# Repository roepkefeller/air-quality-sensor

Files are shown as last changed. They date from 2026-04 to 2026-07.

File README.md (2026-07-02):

# Air Quality Sensor

A DIY open-source air quality monitor built around an [ESP32-C3-WROOM-02](https://documentation.espressif.com/esp32-c3-wroom-02_datasheet_en.pdf), featuring a custom 4-layer PCB with four Sensirion/Bosch sensors, a laser-cut glass top panel, and a 3D-printed holder. Firmware runs on [ESPHome](https://esphome.io) and integrates natively with Home Assistant.

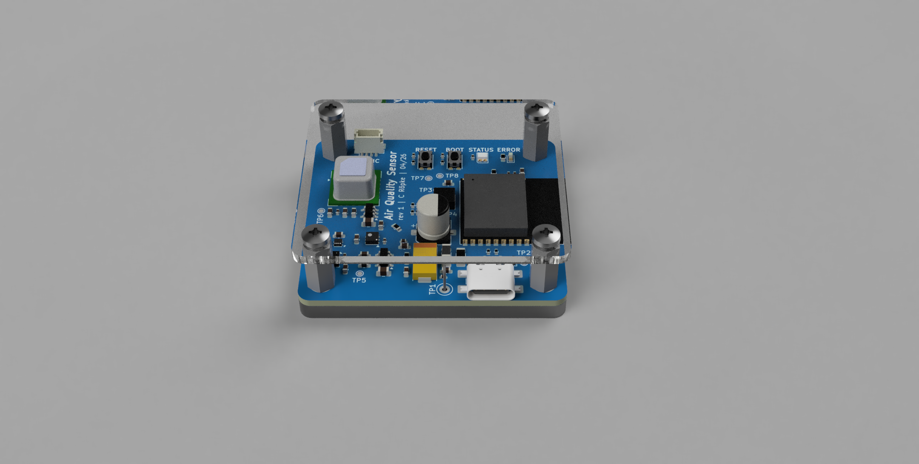
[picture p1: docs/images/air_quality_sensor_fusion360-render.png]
Fusion 360 render


---

## Table of contents

- [What it measures](#what-it-measures)
- [System overview](#system-overview)
- [Hardware design](#hardware-design)
  - [Sensors](#sensors)
  - [Power system](#power-system)
  - [PCB](#pcb)
  - [Enclosure](#enclosure)
- [Assembly](#assembly)
  - [Soldering](#soldering)
  - [I2C addresses](#i2c-addresses)
  - [Power-on checklist](#power-on-checklist)
- [Firmware](#firmware)
  - [Getting started](#getting-started)
  - [LED behavior](#led-behavior)
  - [Web interface](#web-interface)
  - [Diagnostic configs](#diagnostic-configs)
- [Manufacturing](#manufacturing)
- [License](#license)

---

## What it measures

| Sensor | Measurements | Notes | Datasheet |
|---|---|---|---|
| **Sensirion SCD41** | CO₂ (ppm), temperature, humidity | Primary air quality signal | [PDF](https://sensirion.com/media/documents/48C4B7FB/67FE0194/CD_DS_SCD4x_Datasheet_D1.pdf) |
| **Sensirion SGP41** | VOC Index (1–500), NOx Index (1–500) | Fallback if SCD41 unavailable | [PDF](https://sensirion.com/media/documents/5FE8673C/61E96F50/Sensirion_Gas_Sensors_Datasheet_SGP41.pdf) |
| **Sensirion SHT40** | Temperature (±0.2 °C), humidity (±1.8 %RH) | Reference for sensor compensation | [PDF](https://sensirion.com/resource/datasheet/sht4x) |
| **Bosch BMP280** | Barometric pressure, temperature | CO₂ altitude compensation source | [PDF](https://www.bosch-sensortec.com/media/boschsensortec/downloads/datasheets/bst-bmp280-ds001.pdf) |

---

## System overview

System overview diagram

The ESP32-C3 sits at the center of the design. All four sensors share a single I2C bus running at 50 kHz. The BMP280 pressure reading feeds the SCD41's ambient pressure compensation input, and the SHT40 temperature and humidity readings feed the SGP41's gas compensation algorithm. This cross-sensor compensation is why all four sensors are present even though some measurements overlap.

---

## Hardware design

### Sensors

**SCD41 — CO₂**

The SCD41 uses photoacoustic NDIR (non-dispersive infrared) technology to measure CO₂ directly. CO₂ is the primary metric for indoor air quality: levels above 1000 ppm are linked to reduced concentration, and above 2000 ppm cause noticeable cognitive effects. The SCD41 includes automatic self-calibration (ASC), which compensates for long-term sensor drift by assuming the sensor sees outdoor-quality air (≈400 ppm) for at least one hour per day. It also accepts an ambient pressure input from the BMP280 to correct for altitude-induced measurement error.

**SGP41 — VOC and NOx**

The SGP41 uses a metal oxide (MOX) sensing element to detect volatile organic compounds and nitrogen oxides. Rather than reporting raw concentrations, it outputs a processed index (1–500) where 100 represents a typical indoor baseline. This makes it well-suited for detecting events like cooking, cleaning products, paint fumes, or combustion without requiring gas-specific calibration. It also serves as the fallback air quality signal when CO₂ data is unavailable — the LED logic prefers CO₂ but degrades gracefully to VOC index.

**SHT40 — Temperature and humidity (reference)**

The SHT40 is the most accurate temperature and humidity sensor on the board. Its readings feed the SGP41's built-in compensation algorithm, which requires accurate ambient conditions to produce reliable VOC and NOx readings. The SHT40 is also the primary source of temperature and humidity data for the Home Assistant dashboard — the SCD41 and BMP280 both have internal temperature sensors, but they run warmer due to self-heating and are less accurate.

All sensors on this board are affected by self-heating from the SGP41's MOX element (which runs an internal heater at ~400 °C), the ESP32-C3 Wi-Fi radio, and the power regulators. The firmware applies empirically calibrated offset corrections: −5.5 °C / +8 %RH for the SHT40, −5.5 °C for the BMP280, and −1.5 °C / +4 %RH for the SCD41. These values may need tuning — place a known-good reference thermometer next to the board, let everything stabilize for 30+ minutes, and adjust the offsets in the YAML until they match.

**BMP280 — Barometric pressure**

The BMP280 adds barometric pressure, which has two uses: it feeds the SCD41's ambient pressure compensation input (NDIR CO₂ sensors read differently at different altitudes), and it provides weather-correlation data for the Home Assistant dashboard.

---

### Power system

The board takes 5 V via USB-C. Any standard USB-C power supply rated ≥1 A works — no USB Power Delivery negotiation is required, and charge-only cables (no data lines) are fine.

The power path is:

**USB-C → TPD2EUSB30 (ESD protection) → PPTC fuse (750 mA self-resetting) → three separate 3.3 V rails**

Three regulators run in parallel off the 5 V bus, each feeding a dedicated load:

- **[TLV62569A](https://www.ti.com/lit/ds/symlink/tlv62569a.pdf)** (synchronous buck converter) → ESP32-C3 and QWIIC connector. The buck is efficient for the ESP32's variable current draw. The QWIIC connector shares this rail, keeping the sensitive sensor LDO rails free from expansion board loads.
- **[TLV755P](https://www.ti.com/lit/ds/symlink/tlv755p.pdf)** (LDO) → SCD41. The SCD41's photoacoustic CO₂ measurement is sensitive to supply noise; a dedicated LDO with a higher current rating than the TPS7A20 keeps its rail clean and isolated.
- **[TPS7A20](https://www.ti.com/lit/ds/symlink/tps7a20.pdf)** (ultra-low-noise LDO, 10 µVRMS) → SGP41, SHT40, and BMP280. The SGP41's MOX element and SHT40's capacitive humidity sensor are especially susceptible to supply noise; the TPS7A20 keeps all three on a single clean rail, isolated from both the buck and the SCD41's LDO.

The **PPTC fuse** is a self-resetting polyfuse rated at 750 mA, protecting the board against overcurrent faults without requiring manual intervention.

---

### PCB

<table>
  <tr>
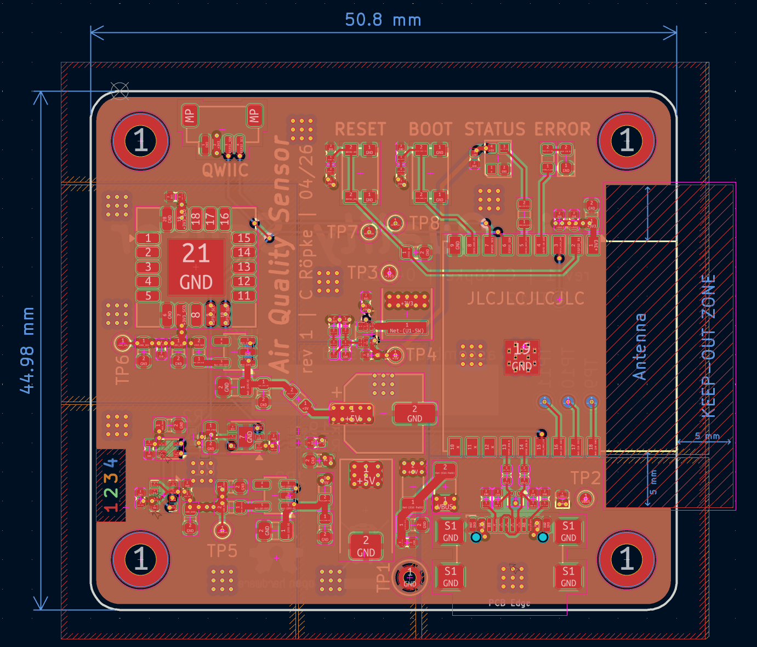
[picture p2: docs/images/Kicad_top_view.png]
KiCad top copper layer
    <td></td>
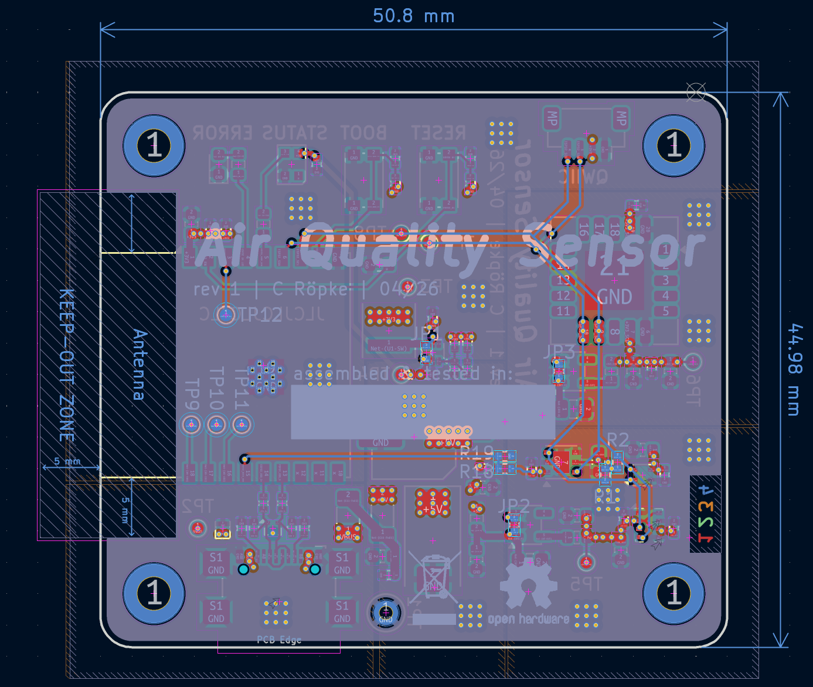
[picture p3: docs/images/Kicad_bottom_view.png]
KiCad bottom copper layer
    <td></td>
  </tr>
  <tr>
    <td align="center"><em>Top copper layer</em></td>
    <td align="center"><em>Bottom copper layer</em></td>
  </tr>
</table>

<table>
  <tr>
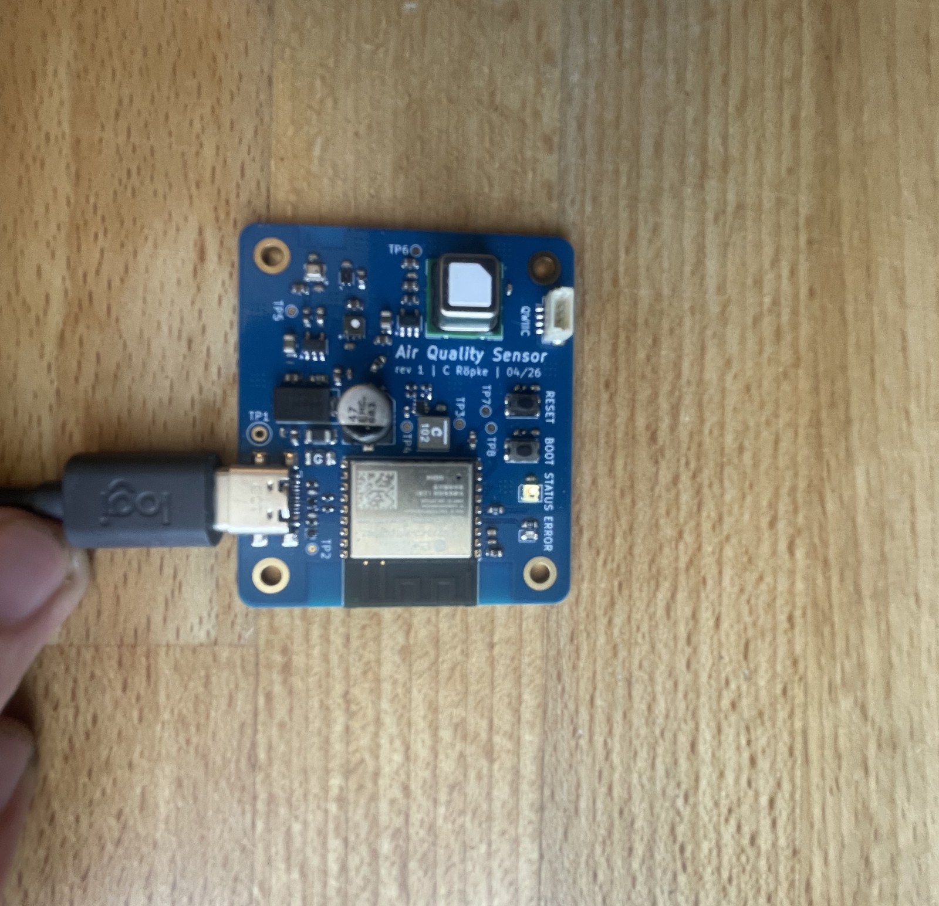
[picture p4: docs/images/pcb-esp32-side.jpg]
PCB component side — ESP32 and sensors
    <td></td>
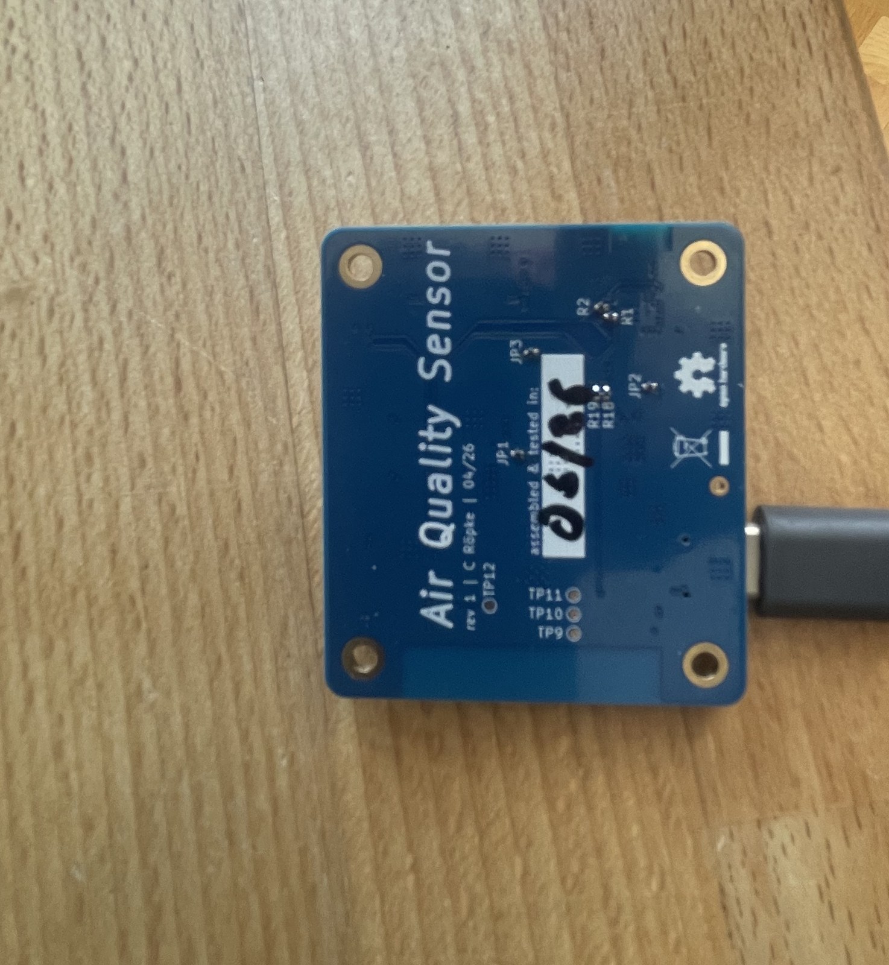
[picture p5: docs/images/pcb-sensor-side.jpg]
PCB bottom side — silkscreen
    <td></td>
  </tr>
  <tr>
    <td align="center"><em>Component side — ESP32, SCD41, regulators</em></td>
    <td align="center"><em>Bottom side — silkscreen</em></td>
  </tr>
</table>

The PCB is a 4-layer board designed in [KiCad](https://www.kicad.org/). Bare boards were manufactured by [JLCPCB](https://jlcpcb.com/) and assembled by hand.

Layer stackup: signal / GND plane / power plane / signal. The dedicated ground and power planes provide clean returns and reduce radiated noise — important given the sensitive gas sensors on the same board.

The board uses a mix of 0402 and 0603 passives, with all ICs in small SMD packages. The custom footprint for the SGP41 (`air_quality_footprints.pretty/`) is included in the repository because it is not in the standard KiCad library.

---

### Enclosure

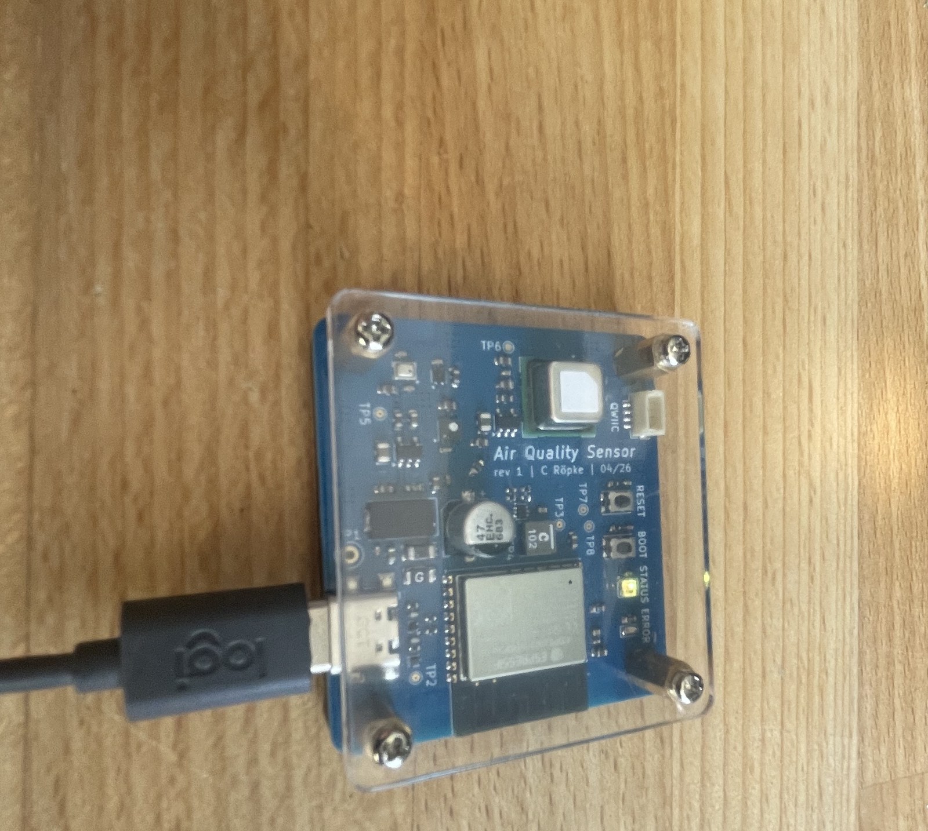
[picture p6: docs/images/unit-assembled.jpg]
Full unit assembled


The enclosure consists of three parts:

**3D-printed holder** (`hardware/enclosure/air_quality_sensor_holder.f3d`, `.stl`): holds the PCB and provides ventilation for the sensors. Print in PLA or PETG at 0.2 mm layer height.

**Laser-cut glass top** (`hardware/enclosure/air_quality_sensor_glass_top.dxf`, `.step`, `.f3d`): 2 mm clear glass, sourced from [Formulor](https://www.formulor.de) using the provided DXF file.

**Standoffs**: [M2.5 × 10 mm male-female hex standoffs](https://www.amazon.de/dp/B0C1FY87PY) (5 mm across flats) mount between the PCB and the glass top. The Fusion 360 model is included at `hardware/enclosure/Standoff mf - M2.5 x 10 across flats 5mm.f3d`.

**Heated inserts**: [M2.5 heat-set inserts](https://www.amazon.de/dp/B0F2TGGBMC) are pressed into the 3D-printed holder with a soldering iron before screwing in the standoffs. This gives the plastic threads much better durability than screwing directly into printed material.

**Power supply and cable**: 5 V/1 A USB-A wall charger + USB-C to USB-A cable. Any charger rated ≥1 A works. Tested with: [RAVIAD USB-C Kabel 1 m (€3.99)](https://www.amazon.de/gp/product/B0GT379MW7) and [18W USB-A Ladegerät, 4er-Pack (€19.98)](https://www.amazon.de/gp/product/B0CRS1YX4S).
<!-- TODO: add photo of USB-C cable + power supply -->

---

## Assembly

### Soldering

All components are SMD. The board was assembled by hand with a soldering iron, flux, and solder paste on the fine-pitch ICs.

Recommended soldering order — smallest and most heat-sensitive first, connectors last:

1. **ESP32-C3-WROOM-02** — the largest IC; solder the pads around the perimeter, then reflow the exposed pad underneath with a hot-air station or by heating the board from below.
2. **TLV62569A, TLV755P, TPS7A20, TPD2EUSB30** — small SOT/WSON packages; drag-solder or use solder paste + hot air.
3. **SGP41** — custom footprint (`air_quality_footprints.pretty/`); ensure the exposed pad underneath is soldered for both mechanical and thermal contact.
4. **SCD41, SHT40, BMP280** — Sensirion LCC packages; reflow carefully, avoid excess heat on the SCD41 optical aperture.
5. **0402/0603 passives** — resistors and capacitors.
6. **USB-C connector, WS2812, LEDs, standoff holes** — connectors and through-board components last.

Use the interactive BOM (`hardware/pcb/air_quality_sensor/bom/ibom.html`) during assembly — it highlights each component on the board overlay and is the easiest way to avoid placing components in the wrong location. Open it locally in any browser, no server required.

The schematic PDF (`hardware/pcb/air_quality_sensor/air_quality_sensor-schematic.pdf`) is the reference for component values and net names.

### I2C addresses

| Sensor | I2C address | Configurable? |
|---|---|---|
| SCD41 | 0x62 | No |
| SGP41 | 0x59 | No |
| SHT40 | 0x44 | No |
| BMP280 | 0x76 | Via SDIO pin (0x76 or 0x77) |

The firmware enables I2C bus scanning on boot (`scan: true`). With a serial monitor connected, boot log output will list all detected addresses — a quick way to confirm all four sensors are soldered correctly and communicating before flashing the full config.

### Power-on checklist

Before flashing for the first time:

1. **Visual inspection** — check for solder bridges on the ESP32 and sensor pads under magnification.
2. **Continuity check** — verify no short between the three 3.3V rails, and no short between any rail and GND.
3. **Apply 5V via USB-C** — measure voltage on each 3.3V rail with a multimeter before the ESP32 is powered. Expected: ~3.3V on all three rails.
4. **Check quiescent current** — with sensors powered but ESP32 not yet flashed, current draw should be low (a few mA). A high reading suggests a solder bridge or incorrect component.
5. **Flash firmware** — once voltage rails check out, proceed to the firmware getting started section.
6. **Verify I2C scan** — open the serial monitor and confirm all four sensor addresses appear in the boot log.

---

## Firmware

The firmware is a single [ESPHome](https://esphome.io) YAML configuration. ESPHome compiles it to a native binary for the ESP32-C3 and handles OTA updates, the web server, and the Home Assistant native API automatically.

### Getting started

**Prerequisites:** ESPHome installed (`pip install esphome` or via the Home Assistant add-on).

1. Copy `firmware/secrets.yaml.example` to `firmware/secrets.yaml` and fill in all four values:

   ```yaml
   wifi_ssid: "your-network"
   wifi_password: "your-password"
   api_encryption_key: "your-base64-encryption-key"
   ota_password: "your-ota-password"
   ```

   The `api_encryption_key` is a 32-byte random key used to encrypt the connection between ESPHome and Home Assistant. Generate one with:

   ```bash
   openssl rand -base64 32
   ```

   Alternatively, run `esphome wizard firmware/air-quality-sensor.yaml` and ESPHome will generate and fill in all secrets interactively.

   The `ota_password` can be any string — you'll be prompted for it when pushing firmware updates over the air.

2. Flash via USB (first time):

   ```bash
   cd firmware
   esphome run air-quality-sensor.yaml
   ```

3. All subsequent updates are over-the-air automatically.

**Home Assistant:** once on the network the device is auto-discovered via the native API. Go to Settings → Integrations and accept the discovered device. All sensors, the fault indicator, and the LED control appear as entities immediately.

---

### LED behavior

The WS2812 RGB LED on the board gives an at-a-glance air quality reading. The firmware prefers CO₂ from the SCD41 as the primary signal; if that sensor is unavailable, it falls back to the VOC index from the SGP41.

| Color | CO₂ (preferred) | VOC Index (fallback) |
|---|---|---|
| 🟢 Green | < 800 ppm | < 150 |
| 🟡 Yellow | 800–1200 ppm | 150–250 |
| 🔴 Red | > 1200 ppm | > 250 |

Brightness defaults to 25% on first boot and is then fully user-controlled from Home Assistant. The chosen brightness persists across reboots. The LED can also be turned on/off from HA — the on/off state persists independently of brightness. Color updates are intentionally instant (no transition fade) so the reading snaps to the new value as soon as a sensor reports.

The LED driver is activated 5 seconds after boot to avoid a crash in the WS2812 driver before its internal buffer is initialized. During this window the LED stays off regardless of sensor data.

A second red LED (the fault LED) lights up whenever any sensor stops reporting valid data. It re-evaluates every 30 seconds as a backstop against sensors going silently missing.

---

### Web interface

The device runs a built-in web server on port 80. Navigate to `http://air-quality-sensor.local` (or the device's IP) in any browser on the same network to see all sensor readings and control buttons without Home Assistant.

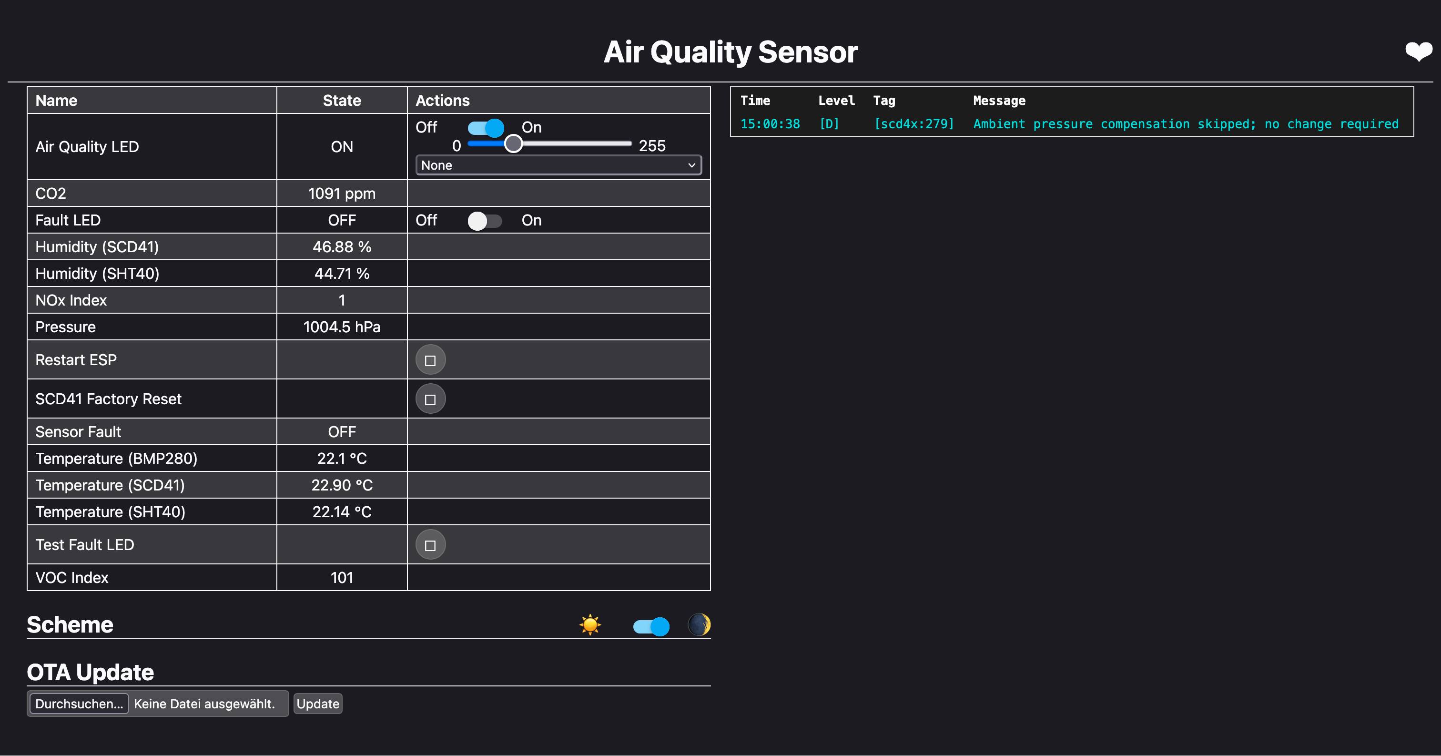
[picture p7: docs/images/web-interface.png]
Web interface


Diagnostic buttons available in the web UI and in Home Assistant:

| Button | Effect |
|---|---|
| **SCD41 Factory Reset** | Clears the SCD41's calibration history and restarts the ESP32. Use if the CO₂ readings look wrong after a long transport or storage period. |
| **Test Fault LED** | Turns the fault LED on for 2 seconds — useful for confirming the LED is soldered and working. |
| **Restart ESP** | Reboots the ESP32. |

If the device cannot reach your Wi-Fi network it falls back to an access point: SSID `Air-Quality Fallback`, password `configureme`. Connect to it and navigate to `http://192.168.4.1` to reconfigure.

---

### Diagnostic configs

Two additional ESPHome configs are included for debugging the SCD41:

| File | Purpose |
|---|---|
| `diagnostic-scd41-only.yaml` | Runs only the SCD41 in isolation — useful for ruling out I2C address conflicts |
| `diagnostic-scd41-deep.yaml` | Extended SCD41 diagnostics with verbose sensor logging |

Flash a diagnostic config the same way as the main config:

```bash
esphome run firmware/diagnostic-scd41-only.yaml
```

---

## Manufacturing

PCB production files are in `hardware/pcb/air_quality_sensor/jlcpcb/`:

| File | Purpose |
|---|---|
| `gerber/GERBER-air_quality_sensor.zip` | Upload to JLCPCB (or any fab) to order the bare PCB |
| `production_files/BOM-air_quality_sensor.csv` | Bill of materials — use for sourcing components |
| `production_files/CPL-air_quality_sensor.csv` | Component placement file — reference for hand assembly positioning |

Order the bare PCB from JLCPCB using the Gerber zip. Source components separately (Mouser, LCSC, DigiKey) using the BOM, then assemble by hand — see the [Assembly](#assembly) section above for the recommended process.

The schematic PDF (`hardware/pcb/air_quality_sensor/air_quality_sensor-schematic.pdf`) and interactive BOM (`bom/ibom.html`) are the primary references during assembly.

---

## License

Hardware (PCB schematics, layout, enclosure files) is licensed under the [CERN Open Hardware Licence Version 2 – Strongly Reciprocal (CERN-OHL-S-2.0)](https://ohwr.org/cern_ohl_s_v2.txt).

Firmware is licensed under the [MIT License](https://opensource.org/licenses/MIT).

In short: you can use, modify, and manufacture this design freely — including commercially — as long as any modifications to the hardware are released under the same licence.

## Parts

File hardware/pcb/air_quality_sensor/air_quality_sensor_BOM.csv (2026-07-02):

Reference | Qty | DNP | Footprint | Manufacturer (MFR) | Value | Manufacturer Part Number (MPN) | Datasheet | Comments
C1 | 1 |  | Capacitor_SMD:C_0402_1005Metric | KYOCERA AVX | 4.7µ/10V/X5R | 0402ZD475KAT2A
C2,C3,C5,C12,C13,C21,C22,C25,C30,C31,C34 | 11 |  | Capacitor_SMD:C_0402_1005Metric | YAGEO | 100n/10V/X5R | CC0402KPX5R6BB104
C4,C9 | 2 |  | Capacitor_SMD:C_0402_1005Metric | KEMET | 10p/10V/C0G | C0402C100J8GACTU
C6,C29 | 2 |  | Capacitor_SMD:C_0402_1005Metric | Murata | 22µ/10V/X5R | GRM158R61A226ME15D
C7,C8,C11,C17,C18,C19,C20,C24,C26,C28,C32,C33 | 12 |  | Capacitor_SMD:C_0603_1608Metric | YAGEO | 1µ/10V/X5R | CC0603KRX5R6BB105
C10 | 1 | DNP | Capacitor_SMD:C_0402_1005Metric | KEMET | 10p/10V/C0G | C0402C100J8GACTU
C14,C27 | 2 |  | Capacitor_SMD:C_0805_2012Metric | Murata | 47µ/10V/X5R | GRM21BR61A476ME15L
C15 | 1 |  | Capacitor_Tantalum_SMD:CP_EIA-7343-20_Kemet-V | Kyocera AVX | 100µ/16V | TCJY107M016R0050
C16 | 1 |  | Capacitor_SMD:C_0402_1005Metric | YAGEO | 1µ/10V/X5R | CC0402KPX5R6BB104
C23 | 1 |  | Capacitor_SMD:CP_Elec_6.3x7.7 | Panasonic | 47u/16V/20% | EEE-HC1E470XP
D1 | 1 |  | Diode_SMD:D_SOD-882 | ST Microelectronics | ESDALC5 | ESDALC5-1BM2 | kicad-embed://esdalc5-1bm2.pdf
D2 | 1 |  | LED_SMD:LED_0603_1608Metric | LITEON | LED 0603 red | LTST-C190EKT | https://www.mouser.com/catalog/specsheets/lite-on_lites05751-1.pdf
D3 | 1 |  | LED_SMD:LED_WS2812B-2020_PLCC4_2.0x2.0mm | Worldsemi | WS2812 | WS2812B-2020 | https://cdn-shop.adafruit.com/product-files/4684/4684_WS2812B-2020_V1.3_EN.pdf
F1 | 1 |  | Fuse:Fuse_1206_3216Metric | Littelfuse | PPTC 8V 750mA | 1206L075THYR | https://www.littelfuse.com/assetdocs/resettable-ptcs-1206l-datasheet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
FB1,FB3 | 2 |  | Inductor_SMD:L_0603_1608Metric | Murata Electronics | 1k@100MHz | BLM18KG102SN1D | https://www.lcsc.com/datasheet/C160982.pdf
FB2 | 1 |  | Inductor_SMD:L_1206_3216Metric | Murata Electronics | 1k@100MHz | BLM31KN102SH1L | https://www.mouser.de/datasheet/3/76/1/QNFA9148.pdf
J1 | 1 |  | Connector_USB:USB_C_Receptacle_GCT_USB4110 | GCT | USB4110 | USB4110-GF-A | https://www.usb.org/sites/default/files/documents/usb_type-c.zip
J2 | 1 |  | Connector_JST:JST_SH_BM04B-SRSS-TB_1x04-1MP_P1.00mm_Vertical | JST | QWIIC Connector | BM04B-SRSS-TB(LF)(SN)
JP1,JP2,JP3 | 3 |  | Resistor_SMD:R_0402_1005Metric |  | 0/1%
L1 | 1 |  | Inductor_SMD:L_Coilcraft_XxL4020 | Coilcraft | 1uH/20%/9.6A | XEL4020-102MEC | https://4donline.ihs.com/images/VipMasterIC/IC/COLC/COLC-S-A0011921176/COLC-S-A0012448959-1.pdf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
R1,R2 | 2 |  | Resistor_SMD:R_0402_1005Metric |  | 4.7k/1%
R3,R9 | 2 |  | Resistor_SMD:R_0402_1005Metric |  | 22/1%
R4,R5 | 2 |  | Resistor_SMD:R_0402_1005Metric |  | 5.1k/1%
R6 | 1 |  | Resistor_SMD:R_0402_1005Metric |  | 270k/1%
R7 | 1 |  | Resistor_SMD:R_0402_1005Metric |  | 180k/1%
R8 | 1 |  | Resistor_SMD:R_0402_1005Metric |  | 100k/1%
R10,R12 | 2 |  | Resistor_SMD:R_0603_1608Metric |  | 330/1%
R11 | 1 |  | Resistor_SMD:R_0603_1608Metric |  | 36/1%
R13 | 1 |  | Resistor_SMD:R_0603_1608Metric |  | 0/1%
R14,R15,R18,R19 | 4 |  | Resistor_SMD:R_0402_1005Metric |  | 10k/1%
SW1,SW2 | 2 |  | Button_Switch_SMD:SW_Push_1P1T_NO_CK_KMR2 | C&K | Push_Button | KMR621NG_LFS | https://www.ckswitches.com/media/1907/kmr6.pdf
U1 | 1 |  | Package_TO_SOT_SMD:SOT-563 | Texas Instruments | TLV62569A | TLV62569ADRLT | https://www.ti.com/lit/gpn/tlv62569a
U2 | 1 |  | Sensor_Humidity:Sensirion_DFN-4_1.5x1.5mm_P0.8mm_SHT4x_NoCentralPad | Sensirion | SHT40 | SHT40-AD1B-R2 | https://www.mouser.de/datasheet/3/1278/1/HT_DS_Datasheet_SHT4x_5.pdf
U3 | 1 |  | Package_LGA:Bosch_LGA-8_2x2.5mm_P0.65mm_ClockwisePinNumbering | Bosch Sensortec | BMP280 | BMP280 | https://cdn-shop.adafruit.com/datasheets/BST-BMP280-DS001-11.pdf
U4 | 1 |  | Package_TO_SOT_SMD:Texas_DRT-3 | Texas Instruments | TPD2EUSB30 | TPD2EUSB30DRTR | http://www.ti.com/lit/ds/symlink/tpd2eusb30a.pdf
U5 | 1 |  | Sensor:Sensirion_SCD4x-1EP_10.1x10.1mm_P1.25mm_EP4.8x4.8mm | Sensirion | SCD41 | SCD41-D-R2 | https://sensirion.com/media/documents/E0F04247/631EF271/CD_DS_SCD40_SCD41_Datasheet_D1.pdf | very temperature sensitive! Use low-temp solder paste!
U6 | 1 |  | air_quality_footprints:XDCR_SGP41-D-R4 | Sensirion | SGP41 | SGP41-D-R4 | https://sensirion.com/media/documents/5FE8673C/61E96F50/Sensirion_Gas_Sensors_Datasheet_SGP41.pdf
U7 | 1 |  | Package_TO_SOT_SMD:SOT-23-5 | Texas Instruments | TPS7A20 | TPS7A2033PDBVR | https://www.ti.com/lit/ds/symlink/tps7a20.pdf
U8 | 1 |  | RF_Module:ESP32-C3-WROOM-02 | Espressif | ESP32-C3-WROOM-02 | ESP32-C3-WROOM-02 | https://www.espressif.com/sites/default/files/documentation/esp32-c3-wroom-02_datasheet_en.pdf
U9 | 1 |  | Package_TO_SOT_SMD:SOT-23-5 | Texas Instruments | TLV75533P | TLV75533PDBVR | https://www.ti.com/lit/ds/symlink/tlv755p.pdf | Alternative: Diodes Inc. AP2112K-3.3TRG1

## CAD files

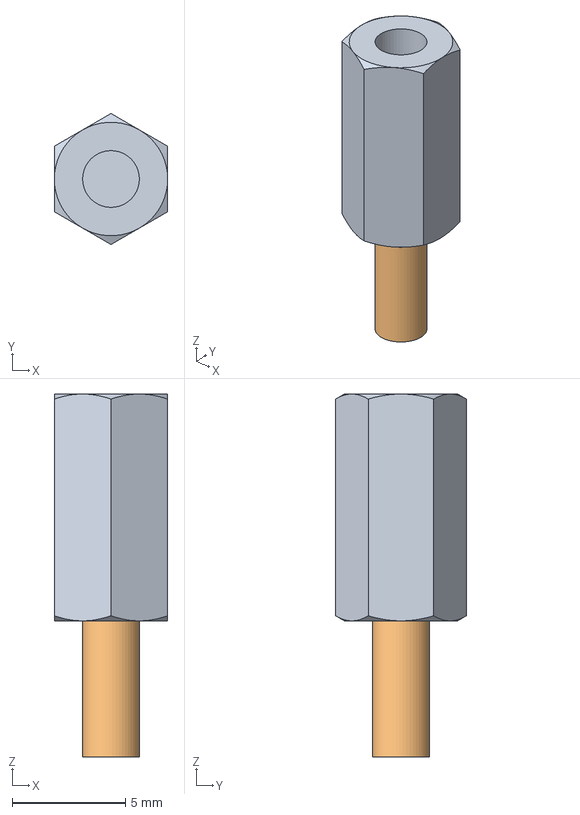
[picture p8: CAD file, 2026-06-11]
hardware/enclosure/Standoff mf - M2.5 x 10 across flats 5mm.step
5.00 x 5.77 x 16.0 mm

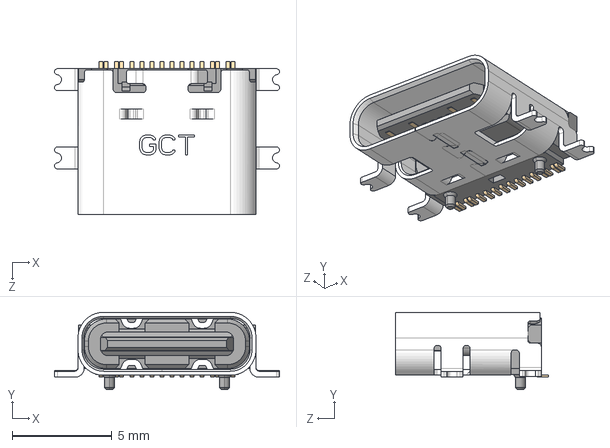
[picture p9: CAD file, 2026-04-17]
hardware/pcb/air_quality_sensor/3dmodels/USB4110-GF-A.step
11.3 x 3.89 x 7.70 mm

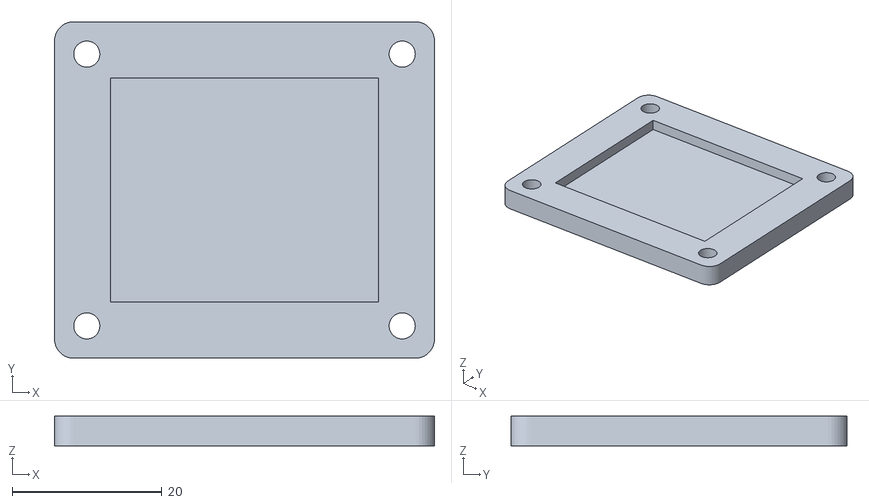
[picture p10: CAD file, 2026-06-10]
hardware/enclosure/air_quality_sensor_holder.stl
50.8 x 45.0 x 4.00

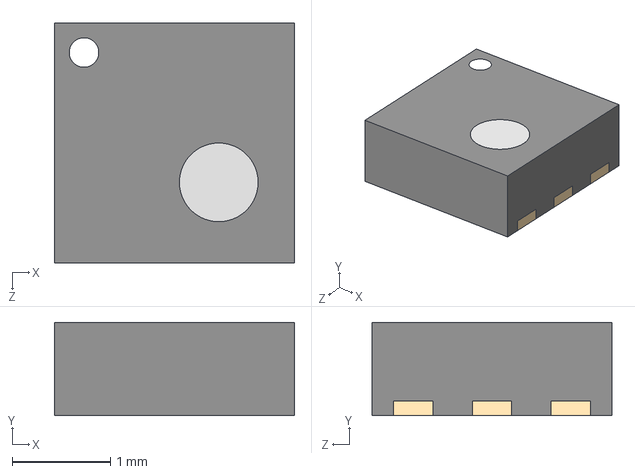
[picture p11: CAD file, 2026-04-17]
hardware/pcb/air_quality_sensor/3dmodels/SGP41-D-R4.step
2.44 x 0.95 x 2.44 mm

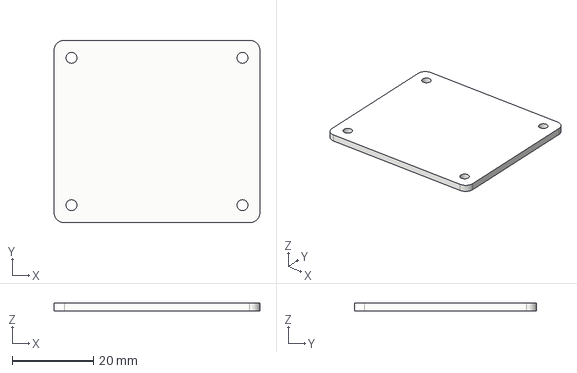
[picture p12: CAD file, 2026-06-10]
hardware/enclosure/air_quality_sensor_glass_top.step
50.8 x 45.0 x 2.00 mm

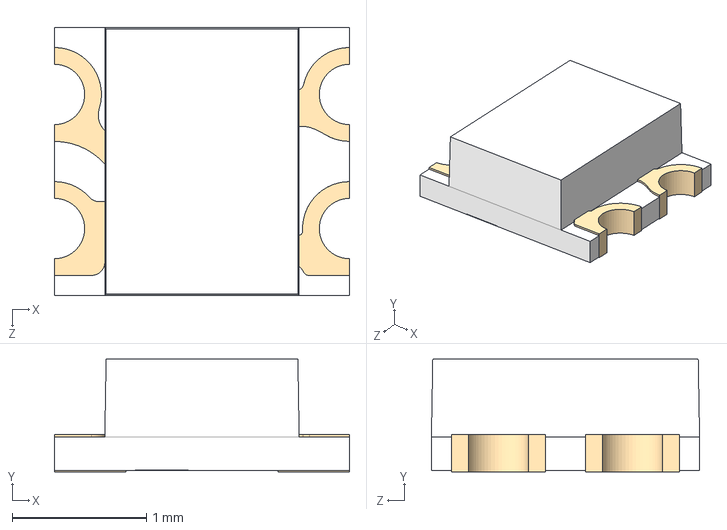
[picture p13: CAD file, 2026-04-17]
hardware/pcb/air_quality_sensor/3dmodels/WS2812-2020--3DModel-STEP-1.STEP
2.20 x 0.84 x 2.00 mm

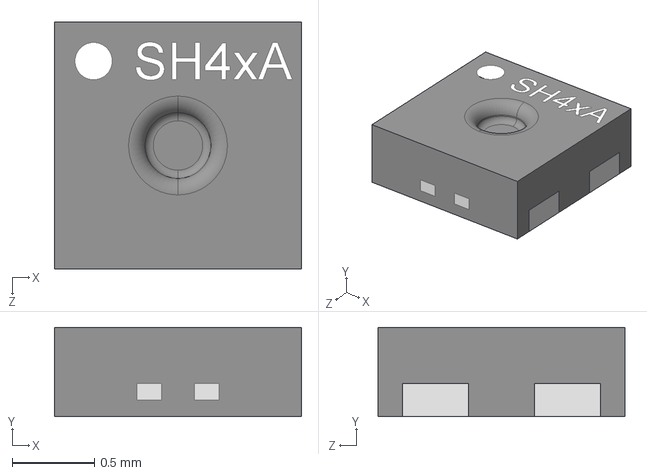
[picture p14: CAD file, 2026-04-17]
hardware/pcb/air_quality_sensor/3dmodels/SHT40-AD1B-R3.STEP
1.50 x 0.541 x 1.50 mm

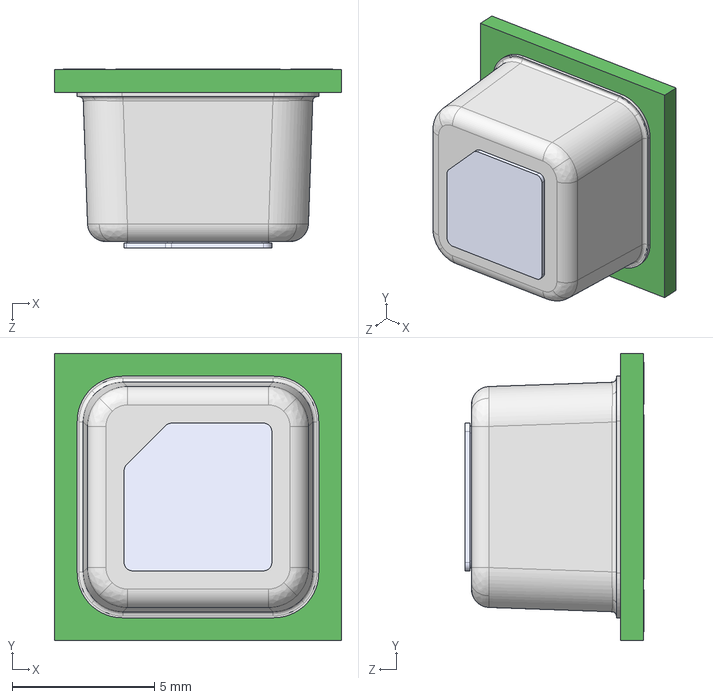
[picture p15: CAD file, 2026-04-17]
hardware/pcb/air_quality_sensor/3dmodels/SCD41-D-R2--3DModel-STEP-369182.STEP
10.1 x 10.1 x 6.31 mm

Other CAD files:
hardware/enclosure/air_quality_sensor_glass_top.dxf
hardware/enclosure/air_quality_sensor_glass_top.f3d
hardware/enclosure/air_quality_sensor_holder.f3d

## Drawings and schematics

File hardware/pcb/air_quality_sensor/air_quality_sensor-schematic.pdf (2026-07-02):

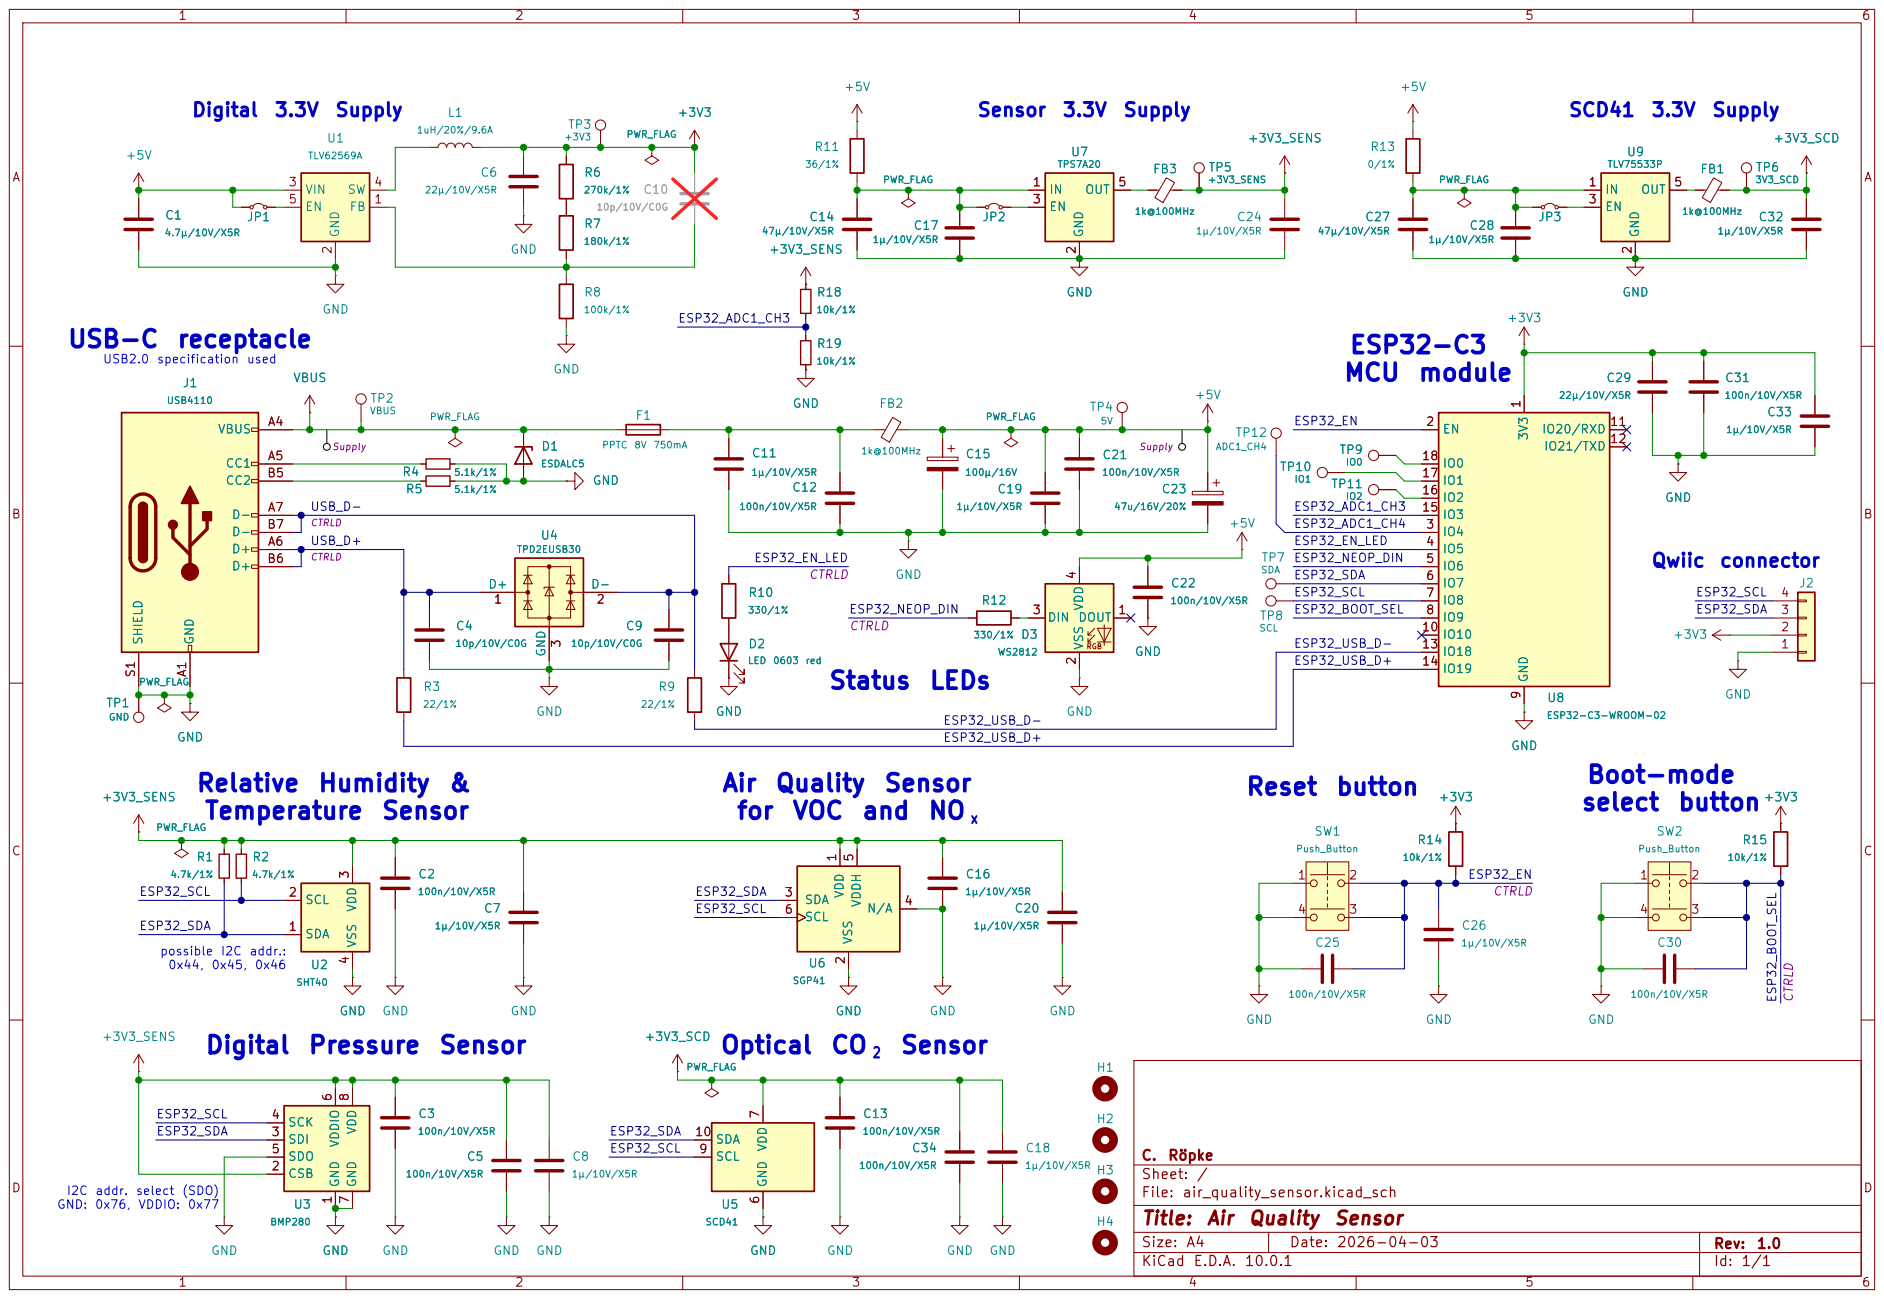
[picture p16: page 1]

Air Quality Sensor
for VOC and NO x Optical CO 2 Sensor
SGP41 VDD

I2C addr. select (SDO) GND: 0x76, VDDIO: 0x77

Size: A4 | Rev: 1.0
KiCad E.D.A. 10.0.1 | Id: 1/1

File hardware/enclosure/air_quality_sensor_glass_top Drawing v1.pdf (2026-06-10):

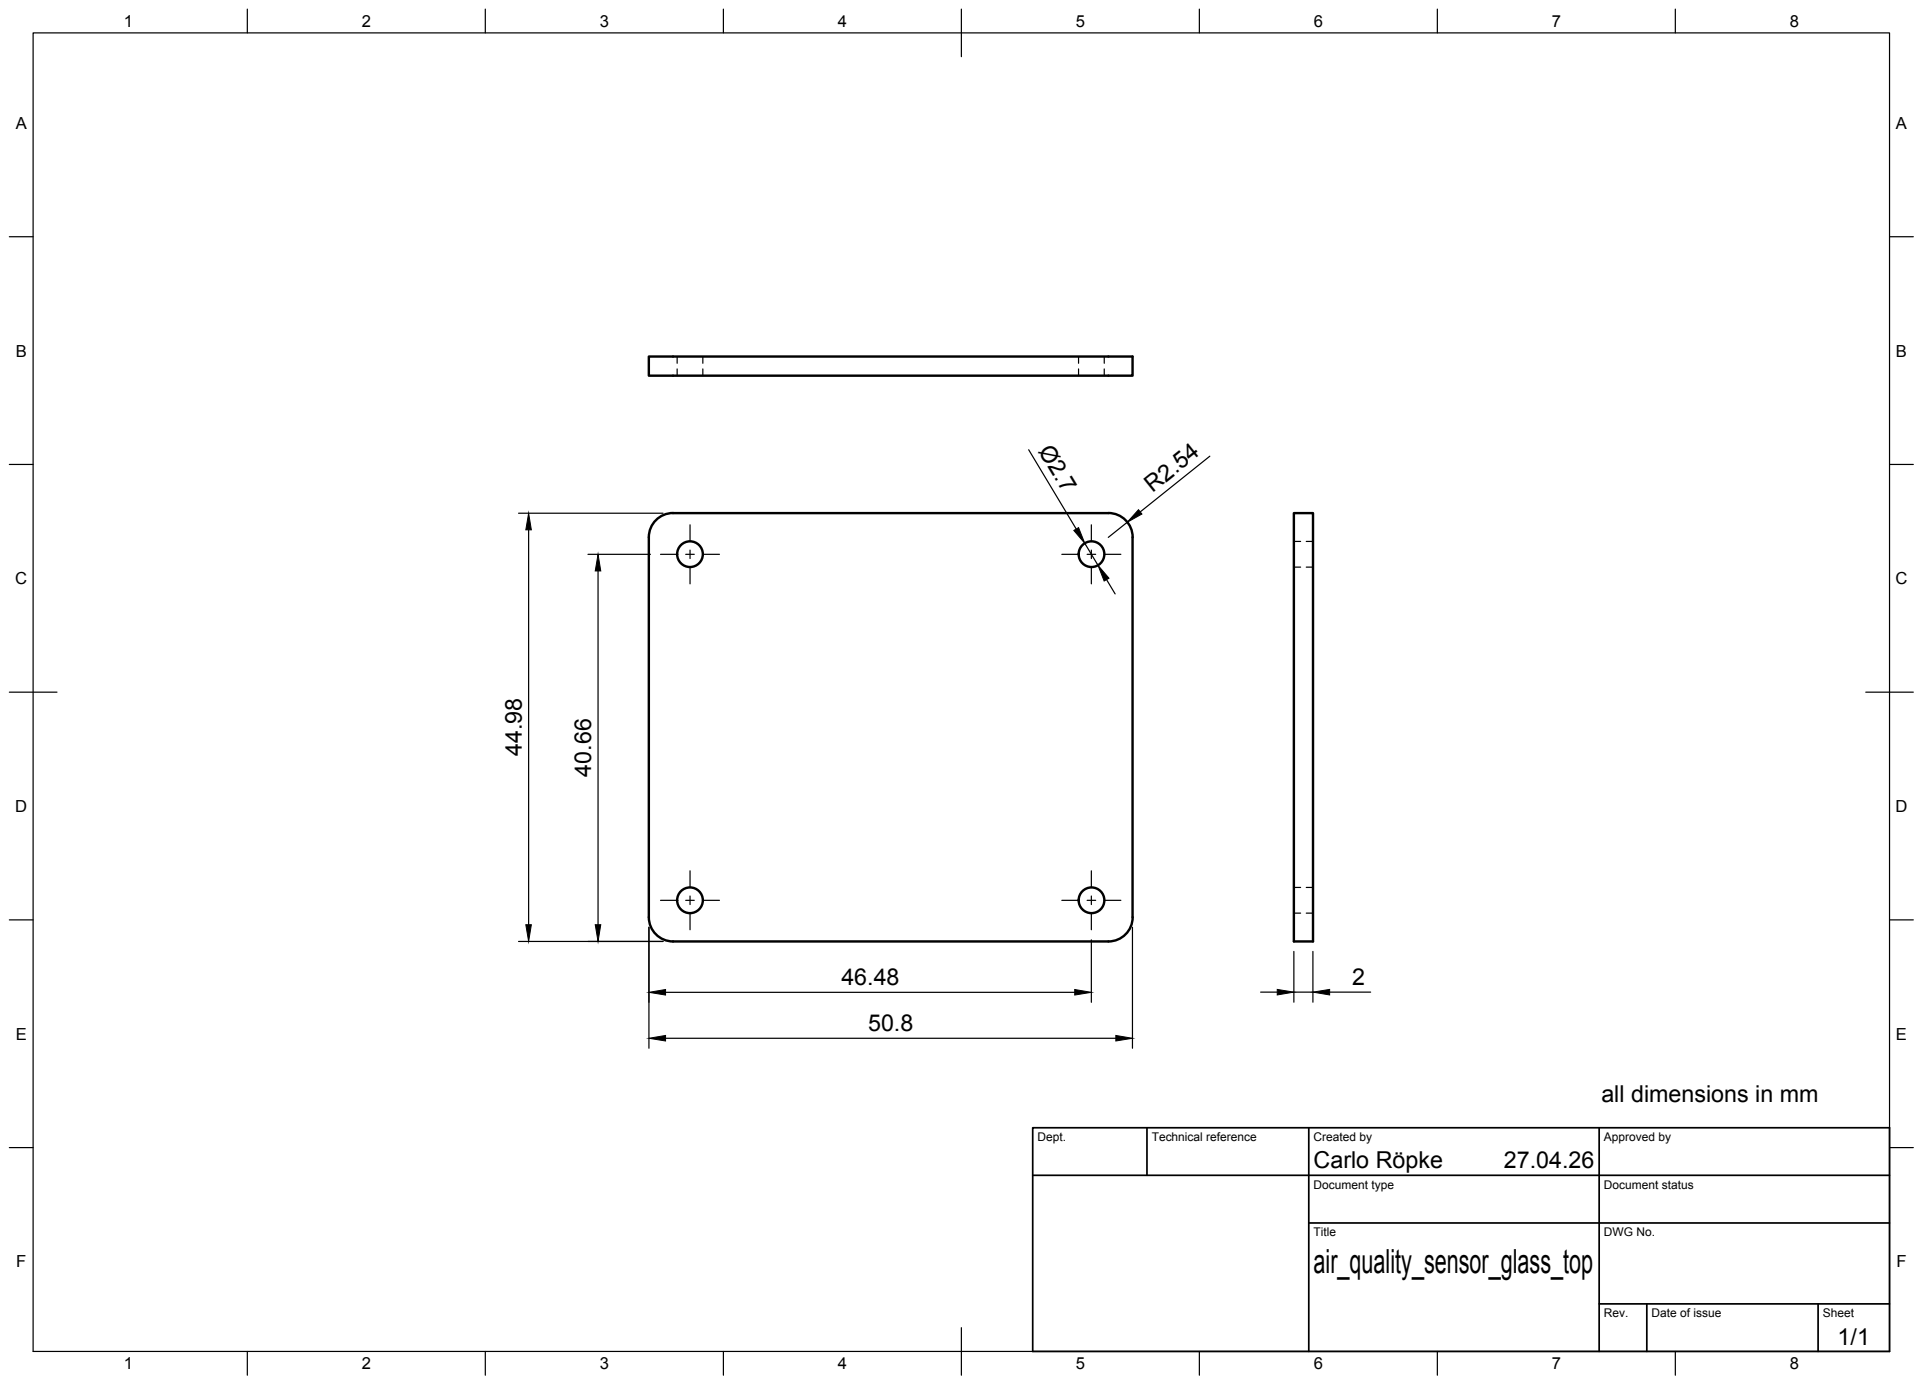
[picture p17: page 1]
Title; DWG No.; Rev.; Date of issue; Sheet

all dimensions in mm

Dept. | Technical reference | Created by Carlo Röpke 27.04.26 | Approved by

Document type | Document status

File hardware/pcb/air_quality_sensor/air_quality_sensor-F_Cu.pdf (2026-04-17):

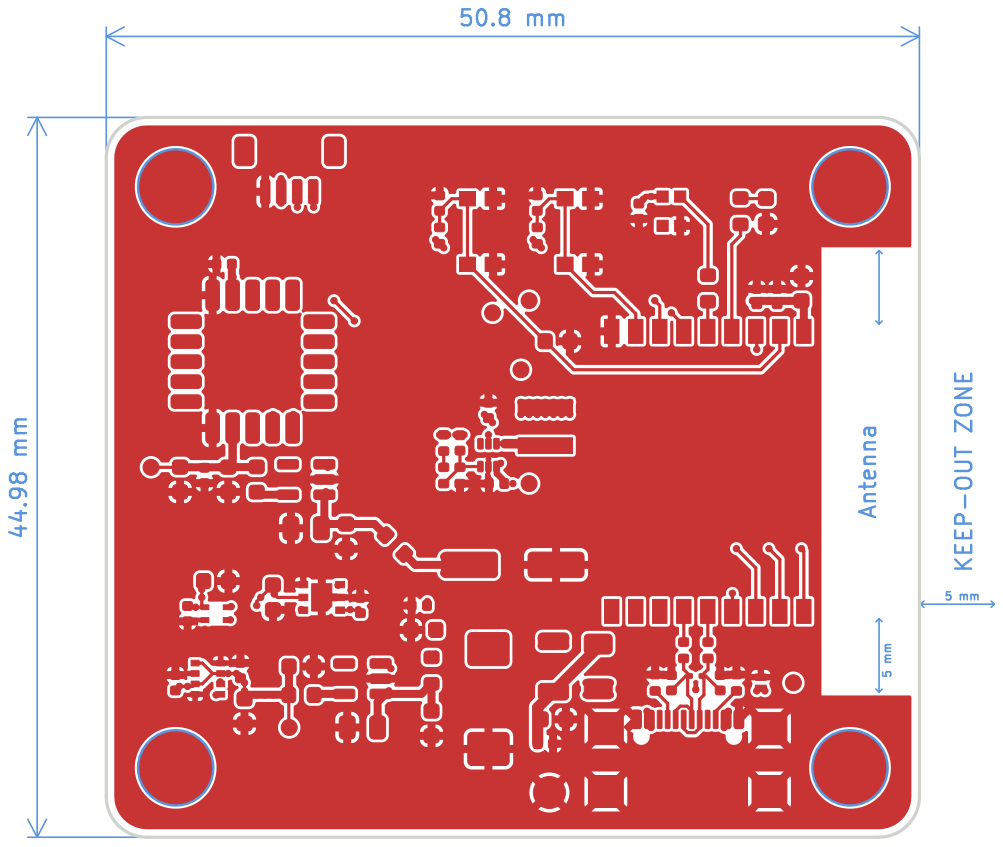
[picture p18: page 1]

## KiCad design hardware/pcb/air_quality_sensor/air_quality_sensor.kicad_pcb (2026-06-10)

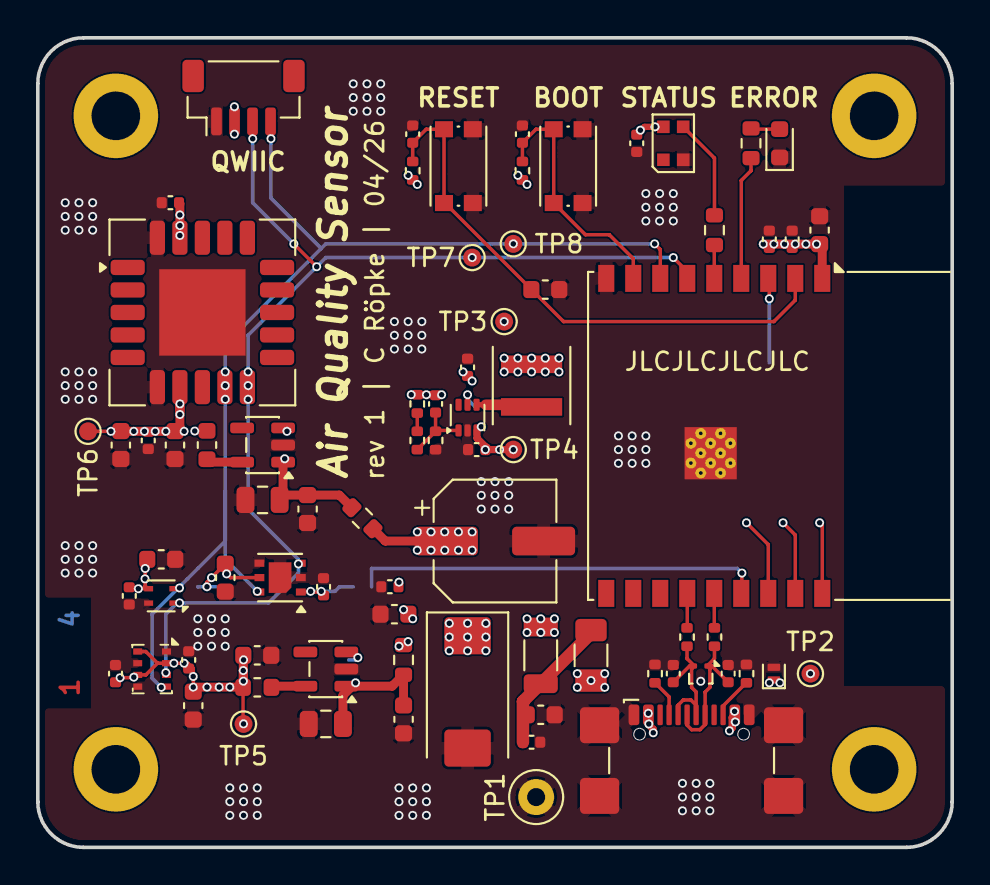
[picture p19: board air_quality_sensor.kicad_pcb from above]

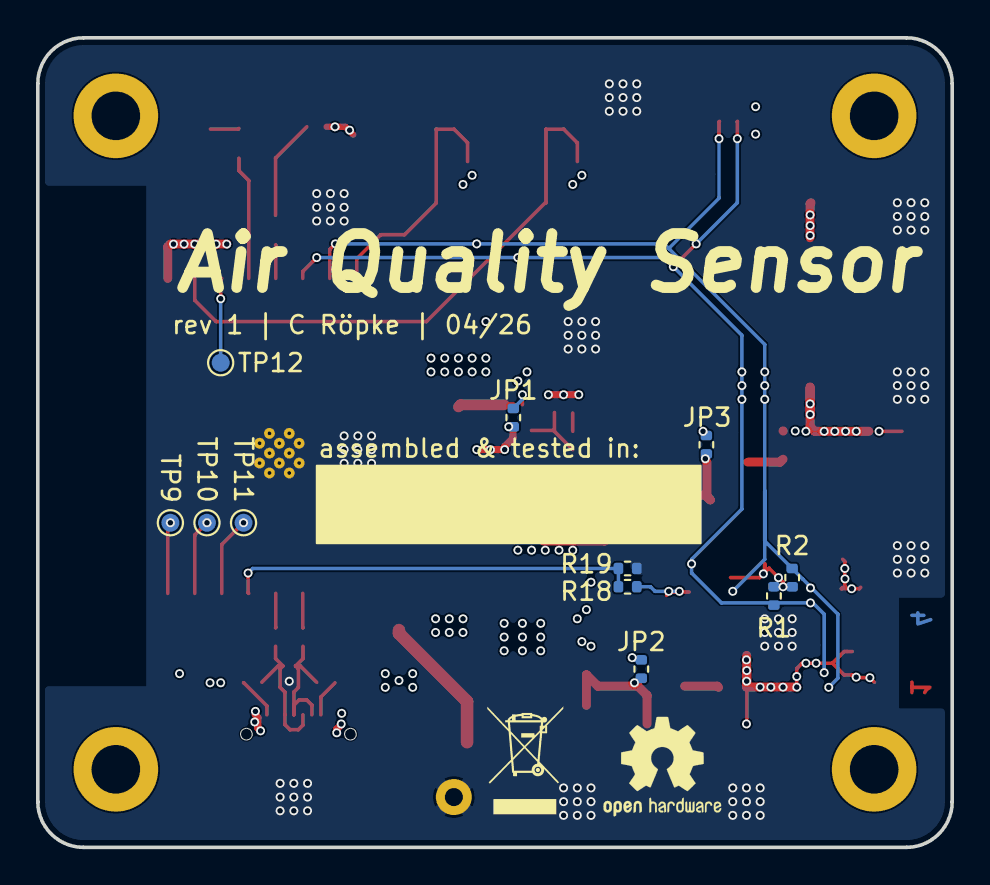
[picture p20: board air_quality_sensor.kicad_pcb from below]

Board: 4 copper layers, 50.8 x 45.0 mm, 91 parts (11 on the bottom side), 36 nets.

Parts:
C1: 4.7µ/10V/X5R; C_0402_1005Metric
C2, C3, C5, C12, C13, C16, C21, C22, C25, C30, C31, C34: 100n/10V/X5R; C_0402_1005Metric
C4, C9, C10: 10p/10V/C0G; C_0402_1005Metric
C6, C29: 22µ/10V/X5R; C_0402_1005Metric
C7, C8, C11, C17, C18, C19, C20, C24, C26, C28, C32, C33: 1µ/10V/X5R; C_0603_1608Metric
C14, C27: 47µ/10V/X5R; C_0805_2012Metric
C15: 100µ/16V; CP_EIA-7343-20_Kemet-V
C23: 47u/16V/20%; CP_Elec_6.3x7.7
D1: ESDALC5; D_SOD-882
D2: LED 0603 red; LED_0603_1608Metric
D3: WS2812; LED_WS2812B-2020_PLCC4_2.0x2.0mm
F1: PPTC 8V 750mA; Fuse_1206_3216Metric
FB1, FB3: 1k@100MHz; L_0603_1608Metric
FB2: 1k@100MHz; L_1206_3216Metric
H1, H2, H3, H4: M3_MountingHole; MountingHole_2.7mm_M2.5_DIN965_Pad
J1: USB4110; USB_C_Receptacle_GCT_USB4110
J2: QWIIC Connector; JST_SH_BM04B-SRSS-TB_1x04-1MP_P1.00mm_Vertical
JP1, JP2, JP3: 0/1%; R_0402_1005Metric
L1: 1uH/20%/9.6A; L_Coilcraft_XxL4020
R1, R2, R14, R15, R18, R19: 10k/1%; R_0402_1005Metric
R3, R9: 22/1%; R_0402_1005Metric
R4, R5: 5.1k/1%; R_0402_1005Metric
R6: 270k/1%; R_0402_1005Metric
R7: 180k/1%; R_0402_1005Metric
R8: 100k/1%; R_0402_1005Metric
R10, R12: 330/1%; R_0603_1608Metric
R11, R13: 36/1%; R_0603_1608Metric
SW1, SW2: Push_Button; SW_Push_1P1T_NO_CK_KMR2
TP1: GND; TestPoint_Loop_D2.50mm_Drill1.0mm
TP2: VBUS; TestPoint_Pad_D1.0mm
TP3: +3V3; TestPoint_Pad_D1.0mm
TP4: 5V; TestPoint_Pad_D1.0mm
TP5: +3V3_SENS; TestPoint_Pad_D1.0mm
TP6: 3V3_SCD; TestPoint_Pad_D1.0mm
TP7: SDA; TestPoint_Pad_D1.0mm
TP8: SCL; TestPoint_Pad_D1.0mm
TP9: IO0; TestPoint_Pad_D1.0mm
TP10: IO1; TestPoint_Pad_D1.0mm
TP11: IO2; TestPoint_Pad_D1.0mm
TP12: ADC1_CH4; TestPoint_Pad_D1.0mm
U1: TLV62569A; SOT-563
U2: SHT40; Sensirion_DFN-4_1.5x1.5mm_P0.8mm_SHT4x_NoCentralPad
U3: BMP280; Bosch_LGA-8_2x2.5mm_P0.65mm_ClockwisePinNumbering
U4: TPD2EUSB30; Texas_DRT-3
U5: SCD41; Sensirion_SCD4x-1EP_10.1x10.1mm_P1.25mm_EP4.8x4.8mm
U6: SGP41; XDCR_SGP41-D-R4
U7, U9: TPS7A20; SOT-23-5
U8: ESP32-C3-WROOM-02

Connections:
+3V3: C6.1, C10.1, C29.1, C31.1, C33.1, J2.2, L1.2, R6.1, R14.1, R15.1, TP3.1, U8.1 (3V3)
+3V3_SCD: C13.1, C18.1, C32.1, C34.1, FB1.2, TP6.1, U5.7 (VDD), U5.19 (VDD)
+3V3_SENS: C2.1, C3.1, C5.1, C7.1, C8.1, C16.1, C20.1, C24.1, FB3.2, R1.1, R2.1, R18.1, TP5.1, U2.3 (VDD), U3.2 (CSB), U3.6 (VDDIO), U3.8 (VDD), U6.1 (VDD), U6.5 (VDDH)
+5V: C1.1, C15.1, C19.1, C21.1, C22.1, C23.1, D3.4 (VDD), FB2.2, JP1.1 (A), R11.1, R13.1, TP4.1, U1.3 (VIN)
/ESP32_ADC1_CH3: R18.2, R19.1, U8.15 (IO3)
/ESP32_ADC1_CH4: TP12.1, U8.3 (IO4)
/ESP32_BOOT_SEL: C30.1, R15.2, SW2.2, U8.8 (IO9)
/ESP32_EN: C25.1, C26.1, R14.2, SW1.2, U8.2 (EN)
/ESP32_EN_LED: R10.1, U8.4 (IO5)
/ESP32_NEOP_DIN: R12.1, U8.5 (IO6)
/ESP32_SCL: J2.4, R2.2, TP8.1, U2.2 (SCL), U3.4 (SCK), U5.9 (SCL), U6.6 (SCL), U8.7 (IO8)
/ESP32_SDA: J2.3, R1.2, TP7.1, U2.1 (SDA), U3.3 (SDI), U5.10 (SDA), U6.3 (SDA), U8.6 (IO7)
/ESP32_USB_D+: R3.2, U8.14 (IO19)
/ESP32_USB_D-: R9.2, U8.13 (IO18)
/USB_D+: C4.1, J1.A6 (D+), J1.B6 (D+), R3.1, U4.1 (D+)
/USB_D-: C9.1, J1.A7 (D-), J1.B7 (D-), R9.1, U4.2 (D-)
GND: C1.2, C2.2, C3.2, C4.2, C5.2, C6.2, C7.2, C8.2, C9.2, C11.2, C12.2, C13.2, C14.2, C15.2, C16.2, C17.2, C18.2, C19.2, C20.2, C21.2, C22.2, C23.2, C24.2, C25.2, C26.2, C27.2, C28.2, C29.2, C30.2, C31.2, C32.2, C33.2, C34.2, D1.2 (A), D2.1 (K), D3.2 (VSS), J1.A1 (GND), J1.A12 (GND), J1.B1 (GND), J1.B12 (GND), J1.S1 (SHIELD), J2.1, R4.2, R5.2, R8.2, R19.2, SW1.1, SW2.1, TP1.1, U1.2 (GND), U2.4 (VSS), U3.1 (GND), U3.5 (SDO), U3.7 (GND), U4.3 (GND), U5.6 (GND), U5.20 (GND), U5.21 (GND), U6.2 (VSS), U6.4 (N/A), U6.7 (EP), U7.2 (GND), U8.9 (GND), U8.19 (GND), U9.2 (GND)
unnamed: C11.1, C12.1, F1.2, FB2.1
unnamed: D2.2 (A), R10.2
unnamed: D3.3 (DIN), R12.2
unnamed: J1.A5 (CC1), R4.1
unnamed: J1.B5 (CC2), R5.1
unnamed: JP1.2 (B), U1.5 (EN)
unnamed: C14.1, C17.1, JP2.1 (A), R11.2, U7.1 (IN)
unnamed: JP2.2 (B), U7.3 (EN)
unnamed: C27.1, C28.1, JP3.1 (A), R13.2, U9.1 (IN)
unnamed: JP3.2 (B), U9.3 (EN)
unnamed: R6.2, R7.1
unnamed: C10.2, R7.2, R8.1, U1.1 (FB)
unnamed: L1.1, U1.4 (SW)
unnamed: FB3.1, U7.5 (OUT)
unnamed: TP9.1, U8.18 (IO0)
unnamed: TP10.1, U8.17 (IO1)
unnamed: TP11.1, U8.16 (IO2)
unnamed: FB1.1, U9.5 (OUT)
VBUS: D1.1 (K), F1.1, J1.A4 (VBUS), J1.A9 (VBUS), J1.B4 (VBUS), J1.B9 (VBUS), TP2.1

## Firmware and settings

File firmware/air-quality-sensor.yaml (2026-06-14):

# ESPHome configuration for custom air quality PCB
# Board: ESP32-C3
# Sensors: BMP280, SCD41, SGP41, SHT40 (all I2C)
# Indicators: WS2812 RGB LED (air quality), standard LED (fault)

esphome:
  name: air-quality-sensor
  friendly_name: Air Quality Sensor
  on_boot:
    priority: -100
    # Wait for all components to fully initialize before allowing any
    # sensor-driven LED updates. This avoids a crash in the WS2812
    # driver if it gets called before its buffer is ready.
    # (restore_mode: RESTORE_DEFAULT_OFF on the light keeps it off
    # at boot, so no explicit turn-off is needed.)
    then:
      - delay: 5s
      - globals.set:
          id: led_ready
          value: 'true'

esp32:
  board: esp32-c3-devkitm-1
  variant: ESP32C3
  framework:
    type: esp-idf

logger:
  level: DEBUG

api:
  encryption:
    key: !secret api_encryption_key

ota:
  - platform: esphome
    password: !secret ota_password

wifi:
  ssid: !secret wifi_ssid
  password: !secret wifi_password
  ap:
    ssid: "Air-Quality Fallback"
    password: "configureme"

captive_portal:

web_server:
  port: 80

# ---------------------------------------------------------------------------
# Globals
# ---------------------------------------------------------------------------
globals:
  - id: brightness_initialized
    type: bool
    restore_value: true
    initial_value: 'false'
  # Tracks whether we've set the LED color at least once since this boot.
  - id: led_first_update_done
    type: bool
    restore_value: false   # resets to false on every boot
    initial_value: 'false'
  # Persists the user's last "on" / "off" choice across reboots.
  - id: user_wants_led_on
    type: bool
    restore_value: true
    initial_value: 'true'
  # Persists the user's chosen brightness explicitly.
  - id: user_brightness
    type: float
    restore_value: true
    initial_value: '0.25'
  # Becomes true 5s after boot, indicating the LED driver is initialized
  # and safe to drive. Avoids a crash if the script fires before then.
  - id: led_ready
    type: bool
    restore_value: false
    initial_value: 'false'

# ---------------------------------------------------------------------------
# I2C bus
# ---------------------------------------------------------------------------
i2c:
  sda: GPIO7
  scl: GPIO8
  scan: true
  frequency: 50kHz

# ---------------------------------------------------------------------------
# Sensors
# ---------------------------------------------------------------------------
sensor:
  # --- SHT40: temperature + humidity (high accuracy) ---
  # The SHT40 is the most accurate T/H sensor on the board, but it sits on
  # a PCB that self-heats from the SGP41 heater (~400°C internally),
  # ESP32-C3 with WiFi, and the regulators. Calibrate the offsets below
  # against a trusted reference thermometer.
  - platform: sht4x
    address: 0x44
    update_interval: 30s
    temperature:
      name: "Temperature (SHT40)"
      id: sht40_temperature
      filters:
        # Subtract self-heating offset. Tune empirically: place a known-good
        # thermometer next to the board, let everything stabilize for 30+
        # minutes, and adjust this until they match.
        - offset: -5.5
    humidity:
      name: "Humidity (SHT40)"
      id: sht40_humidity
      filters:
        # When the board reads ~5°C high, RH reads ~10-15% low because RH
        # is temperature-dependent. We add back a small offset; better
        # accuracy comes from physically separating sensors in next revision.
        - offset: 8.0

  # --- BMP280: pressure + temperature ---
  - platform: bmp280_i2c
    address: 0x76
    update_interval: 30s
    temperature:
      name: "Temperature (BMP280)"
      oversampling: 16x
      filters:
        - offset: -5.5
    pressure:
      name: "Pressure"
      id: bmp280_pressure

  # --- SCD41: CO2, temperature, humidity ---
  - platform: scd4x
    id: scd41_sensor
    address: 0x62
    update_interval: 30s
    measurement_mode: periodic
    # Keep the chip's internal offset at default (4°C). Additional
    # compensation for board self-heating is applied via filter offsets
    # on the individual sensor outputs below, matching how SHT40 and
    # BMP280 handle it.
    ambient_pressure_compensation_source: bmp280_pressure
    co2:
      name: "CO2"
      id: co2_value
      on_value:
        then:
          - script.execute: update_air_quality_led
    temperature:
      name: "Temperature (SCD41)"
      filters:
        # Adjusts for additional board self-heating beyond what the chip's
        # own 4°C internal offset compensates for. Tune to match SHT40.
        - offset: -1.5
    humidity:
      name: "Humidity (SCD41)"
      filters:
        # Higher temp reading on the SCD41 also caused humidity to read low.
        - offset: 4.0
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

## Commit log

2026-04-17 initial commit - rev1 ordered at jlcpcb 04/26
    [BOM-air_quality_sensor.csv, SCD41-D-R2--3DModel-STEP-369182.STEP, SGP41-D-R4.step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]
2026-06-10 changed folder structure
    [BOM-air_quality_sensor.csv, SCD41-D-R2--3DModel-STEP-369182.STEP, SGP41-D-R4.step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]
2026-06-11 reworked folder structure and created first README
    [BOM-air_quality_sensor.csv, SCD41-D-R2--3DModel-STEP-369182.STEP, SGP41-D-R4.step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]
2026-06-14 Fix LED boot crash, persist brightness, add self-heating offsets
    - Guard LED script with 5s boot delay to avoid WS2812 driver crash
    - Persist user brightness in dedicated NVS global instead of remote_values
    - Drop LED transition fade (instant color updates)
    - Add empirical self-heating offsets: SHT40 −5.5 °C/+8 %RH,
    SCD41 −1.5 °C/+4 %RH, BMP280 −5.5 °C
    [air_quality_sensor.kicad_sch]
2026-06-23 changed C16 to 1uF to prevent SGP41 from making weird noises..
    [air_quality_sensor.kicad_sch]
2026-07-02 new schematic pdf to reflect changes from last commits
2026-07-02 also updated BOM to reflect last component changes
    [air_quality_sensor_BOM.csv]
2026-07-02 qwiic port is now on the correct power rail..
2026-07-04 reworked firmware to include more functionality and diagnostics. also added multi-board support and git-based firmware versioning
2026-09-22 detect stuck and drifting sensors, not just dead ones
    The fault check was `has_state() && !isnan(state)`, which only catches a
    sensor that stops publishing. It does not catch the failure that actually
    happened in the field: a BMP280 latched up and kept publishing
    19.8530464172363 C and 1016.51080322266 hPa for 14 days -- min == mean ==
    max across 335 hourly values. Every liveness check stayed green the whole
    time, and only a power cycle (not a software reset) brought the chip back.
    A sensor is now faulted on three dimensions instead of one:
    dead no state / NaN (the original check)
    stuck value has not moved over a 15 min window (new)
    drift disagrees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
2026-09-22 add an on-device test harness for stuck detection
    Verifying the stuck path on real hardware meant waiting out a 20 min boot
    grace plus a 15 min window, and then having no way to actually freeze a
    sensor short of waiting for one to fail.
    Two knobs fix that. The detector counts its window length and boot grace
    in ticks rather than seconds, so `fault_sample_interval` scales both:
    flashing with 2s gives a 1 min window and 80s grace, turning a ~35 min
    test cycle into ~100 seconds.
    A "Debug Freeze BMP280" switch pins the BMP280 values as seen by the
    detector to whatever they read when it was flipped. The sensor itself
    keeps publishing normally, so this isolates the stuck path and proves the
    dete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
2026-09-22 report why the board booted
    "Last Crash Reason" was a placeholder that only ever said "None" -- the
    global was declared and read, but never written.
    It matters more than it looks here. A latched-up sensor is not cleared by
    a software reset, only by actually losing power, so whenever a chip does
    or does not come back the first question is whether the board really was
    power cycled. esp_reset_reason() answers it, and read next to the new
    fault entities it distinguishes "the reboot did not help, pull the plug"
    from "this chip is genuinely failing".
    Kept in its own header because it pulls in an ESP-IDF include, and
    fault_detect.h has to stay compilable on a host for the tests. Set at
    boot prior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
2026-09-22 cut NVS writes for the daily counters by ~15x
    time_green/yellow/red were restore_value globals incremented once a
    second. ESPHome flushes dirty preferences on its own timer (60s by
    default), so that was ~1440 NVS writes a day, every day, for the life of
    the device -- and each one dragged every other preference (brightness,
    thresholds, reboot count) along with it.
    The 1s tick now only touches non-persisted *_live accumulators, and a
    15-minute interval folds them into the persisted base. ~96 writes a day
    instead of ~1440. A crash costs at most 15 minutes of counter, which is
    well inside what these are useful for. The displayed sensors report
    base + live, so nothing changes in Home Assistant.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
2026-09-22 make boost mode speed up the entities people actually read
    Boost mode only re-polled the four hardware sensors. The derived template
    sensors -- Temperature, Humidity, Absolute Humidity, Dew Point, Air
    Quality Score -- stayed at 30s, so pressing "Boost" while cooking made the
    LED and CO2 responsive while the displayed temperature stayed sluggish.
    Those are the entities on the main card.
    The on and off paths were also two near-identical lambdas that had to be
    kept in sync by hand. Both now call one parameterised script, which is
    what makes adding five more components to the list a one-line change.
    The stuck detector's own interval deliberately stays at 30s; see
    fault_sample_interval. The PM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
2026-09-22 take peak values from the consolidated sensors
    The peak trackers read raw sht40_temperature and sht40_humidity, but they
    sit next to the consolidated "Temperature" and "Humidity" entities in Home
    Assistant, so they have to be peaks of those. As written they could report
    an extreme from a sensor the fusion had just dropped for drifting.
    Also gives peak_rh_max the sentinel the other three already had, so it
    reads unavailable before the first measurement instead of claiming 0%.
2026-09-22 add PM sensor watchdog for I2C bus lockups
    The PMSA003I occasionally holds SDA low without disappearing from the I2C
    scan. Reboot after 10 minutes of missing PM2.5 readings; the ESP-IDF bus
    recovery on boot clears it. Exposes the counter as a diagnostic sensor.
2026-09-22 fold the PM sensor into the shared fault model
    The PM watchdog was doing fault detection with its own parallel machinery:
    its own liveness check, its own counter, and an untyped `extra_fault`
    boolean that could only tell the base firmware "something, somewhere, is
    wrong". So the PMSA003I got none of what the onboard sensors got -- no
    per-chip entity, no health percentage, no named entry in Fault Detail, and
    no stuck detection at all.
    It is now a first-class chip. The header gains a notion of optional chips:
    one marked optional stays silent until a package claims it with
    set_installed(), which is how the base firmware and the PM variant share a
    header without the base inventing a PM fault on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
2026-11-09 fix LED pulse stutter: skip no-op writes in update_air_quality_led
    The script runs on every CO2 and VOC reading (~every 15 s, ~2.5 s in boost
    mode). Each run called turn_on()...perform(). ESPHome drops the repeated
    set_effect("Critical Pulse"), so the effect itself keeps running, but
    perform() still does an instant set_immediately_() at user_brightness: it
    aborts the pulse fade in progress and snaps the LED to e.g. 25 %, below
    the pulse's 30 % minimum (or above 80 % at high brightness). That's the
    visible cut-off / bright flash.
    Track the last applied color/brightness/on/pulse state in globals and only
    write when it changes, or when the light's real on/effect state no longer
    matches (manual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
2026-11-09 add pull-based OTA updates from a LAN update server
    - firmware: http_request update entity ("Firmware") polling
    ${update_server}/${device_slug}/manifest.json every 6 h; HA shows it
    under Settings -> Updates, install stays a manual click. project version
    = firmware_version so the manifest comparison works.
    - device-kueche/schlafzimmer/wohnzimmer.yaml pin location + variant per
    board (Kueche = PM) and get separate build dirs; flash.sh accepts them.
    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
2026-11-09 device configs: build_path is relative to .esphome/
    Claude-Session: https://claude.ai/code/session_01NKcKxi2tFS9L3g5KtsRdAU
2026-11-09 update server: keep its full config in tools/update-server/
    nginx site, systemd service + timer, watcher, LXC creation and setup now
    live as real files (byte-identical to CT 106) instead of heredocs. setup.sh
    installs from a checkout and is idempotent, so changing the server means
    editing these files and re-running it.
    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
2026-11-09 README: document board configs, fault model, OTA updates and update server
    - intro + TOC: updates via GitHub releases, fault model
    - Getting started: fix the duplicated step 3, point to board configs
    - new: Board configs, Sensor fault detection (dead/frozen/flat/drift,
    boot behaviour, Debug Freeze test switch, unit tests)
    - entities: Firmware update entity, per-chip faults, Fault Detail, Span,
    Last Reset Reason; PM fault/recovery entities and bus-lockup recovery
    - new: Firmware updates (how it works, releasing, rollback, update server
    in tools/update-server/, why it's built at home, CI), Repository layout
    Claude-Session: https://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
